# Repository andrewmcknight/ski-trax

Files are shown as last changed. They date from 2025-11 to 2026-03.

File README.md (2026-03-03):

# Ski-Trax

Ski-Trax is an embedded tracking node built around the Heltec WiFi LoRa 32 V3. The goal is a rugged device that skiers can use to find their friends/family on the slopes, without needing a phone with cell service.

## Hardware Stack
- **Main MCU:** Heltec WiFi LoRa 32 V3 (ESP32-S3 + SX1262)
- **GNSS:** SparkFun MAX-M10S breakout (I2C)
- **Display:** Adafruit 2.2" TFT (ILI9341 driver) connected through the Adafruit EYESPI breakout (SPI)
- **IMU:** Adafruit BNO055 9-DOF sensor (I2C)
- **Barometer:** Adafruit BMP390 (I2C)
- **Inputs/Outputs:** Three external buttons, piezo buzzer, TFT backlight PWM

## Pin Assignments
| Function | Heltec GPIO | Notes |
|---|---|---|
| I2C SDA | 47 | Shared by MAX-M10S, BNO055, BMP390 |
| I2C SCL | 48 | Shared by MAX-M10S, BNO055, BMP390 |
| TFT SCK | 3 | Hardware SPI via EyeSPI ribbon |
| TFT MOSI | 4 | Hardware SPI via EyeSPI ribbon |
| TFT CS | 7 | |
| TFT D/C | 5 | |
| TFT RST | 6 | |
| TFT Backlight PWM | 2 | Driven with LEDC PWM |
| Button – Dim | 40 | Input with pull-up |
| Button – Buzzer | 41 | Input with pull-up |
| Button – Brighten | 42 | Input with pull-up |
| Piezo Buzzer | 39 | LEDC PWM output |

> Note: LoRa radio is built into the Heltec board.

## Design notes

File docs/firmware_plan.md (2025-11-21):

## Ski-Trax Firmware Plan

### Goals
- Modular, testable firmware targeting Heltec WiFi LoRa 32 v3.
- Clean UI that leverages TFT assets (bitmaps for compass, icons, etc.).
- Feature set split into reusable services (pairing, networking, sensors, rendering).

---

## 1. System Architecture

### Core Tasks (FreeRTOS or cooperative scheduler)
1. **UI Task**
   - Drives TFT updates and handles button events.
   - Maintains a navigation state machine (Startup → Pairing → Session Lobby → Tracking).
2. **Sensor Task**
   - Polls GPS (MAX-M10S), IMU (BNO055), BMP390, battery ADC.
   - Normalizes sensor payloads and updates a shared `SensorSnapshot`.
3. **LoRa Session Task**
   - Handles discovery, pairing, and telemetry exchange.
   - Maintains a `SessionState` model accessible via queues.
4. **Storage Task (optional future)**
   - Persist user nickname, last session ID, calibration data, etc.

### Shared Data Models
- `DeviceProfile { uuid, nickname, hwVersion }`
- `SessionDescriptor { sessionId, hostNickname, memberCount, channel, lastSeen }`
- `PeerState { uuid, nickname, lastLocation, lastUpdateMs, stats }`
- `SensorSnapshot { gpsFix, timestamp, lat/lon, heading, velocity, altitude, batteryPct, batteryIconIdx, imuCalStatus }`

Use mutex-protected structs or message queues for cross-task communication.

---

## 2. Pairing Experience

### 2.1 Startup Flow
1. **Boot Splash**
   - Display logo + firmware version while services come online.
   - Show spinner / progress bar tied to sensor init.
2. **Landing Screen**
   - Two soft buttons: `Create Session` (left) and `Join Session` (right).
   - Always-on top bar showing time/battery/sensor status even during pairing.

### 2.2 Nickname Entry
1. Prompt user after selecting host/join.
2. UI concept: on-screen keyboard (grid) navigated with buttons or a scrollable list of preset names + an "Edit" action.
3. Persist nickname in NVS for future boots.

### 2.3 Session Creation (Host)
- **UI**
  - After nickname: display “Broadcasting Session…” with a session code (short hash) and a list of connected members.
  - Accept button to “Start Tracking” once at least one joiner is connected (optional skip allowed).
- **Networking**
  - Host advertises `SESSION_BEACON` every 500 ms with:
    - Session ID, host UUID, channel (LoRa frequency/spreading factor), session capabilities.
    - Current member count and uptime.
  - On join request, host replies with `SESSION_ACCEPT` including encryption keys/nonce if using secure packets.

### 2.4 Session Joining
- **UI**
  - Show scrolling list of detected sessions with strength indicators (RSSI) and host names.
  - Selecting a session sends join request; show progress indicator while waiting for `SESSION_ACCEPT`.
- **Networking**
  - Device sends `JOIN_PROBE` broadcast while scanning for beacons (listen cycle ~3s).
  - When beacons received, populate list (expire entries after ~5 s of silence).
  - On selecting session, send `JOIN_REQUEST {nickname, uuid, capabilities}`.
  - Await `SESSION_ACCEPT` (with session parameters) or `SESSION_DENY`.

### 2.5 Behind-the-Scenes Considerations
- Use unique 64-bit session IDs derived from host UUID + uptime millis.
- Include CRC and simple reliability (ack/retry) for pairing messages.
- Maintain state machine:
  - `Idle → NicknameEntry → (Host|Join) → Beaconing/Scanning → Lobby`.
- Provide hooks for future encryption key exchange (Diffie-Hellman or pre-shared key).

---

## 3. Tracking Experience

### 3.1 Session Lobby
- Shows roster tiles (nickname, status, last fix).
- Host can start/stop session; joiners wait for start signal.
- Behind the scenes, LoRa task flips from pairing channel to tracking channel and begins periodic position broadcast.

### 3.2 Tracking Screen Layout
```
┌───────────────────────────── Top Bar (persistent) ───────────────────────────┐
│   HH:MM (GPS)     Battery Icon     Sensor Icons (GNSS, IMU, LoRa, BMP)       │
├──────────────────────────────── Content Region ─────────────────────────────┤
│                                                                             │
│   [Peer Name + status]                                                      │
│   [Compass card (full screen) | overlays]                                   │
│   [Distance Icon + value | Relative Bearing text | Altitude icon + delta]   │
│   [Last update time (“15s ago”)]                                            │
│                                                                             │
├──────────────────────────── Bottom Buttons/Indicators ───────────────────────┤
│   [< Prev Member]           [Center/Home]           [Next Member >]          │
└─────────────────────────────────────────────────────────────────────────────┘
```

### 3.3 Button Mapping
- **Left/Right external buttons**: cycle through peers (wrap-around).
- **Center button**: toggles detail overlay (compass vs. map view in future).
- **Long-press combos**: e.g., hold left+right to open session menu.

### 3.4 Data Presentation
- **Compass**: use 36-direction bitmaps with overlays:
  - Add arrow/label pointing toward selected peer’s bearing relative to device heading.
  - Optionally show mini-map dot layout in future (reserve screen layer).
- **Distance/Altitude**: use custom icons (see Section 5) with values (e.g., `1.2 km`, `+80 m`).
- **Last Update**: relative time string (e.g., `Updated 12s ago`). If stale (>60s), highlight in yellow/red.
- **Peer Status**: include indicators for battery low, no fix, etc.

### 3.5 Networking (Tracking Mode)
- Each member broadcasts `TRACK_UPDATE` every X seconds (adjustable, default 2 s when moving, 5 s idle).
- Payload includes:
  - Timestamp, GPS lat/lon/alt, horizontal + vertical accuracy, heading, speed.
  - Sensor flags/battery level.
  - Sequence number for packet loss detection.
- Received updates stored in `PeerState` list; UI uses freshest data.
- Out-of-date peers flagged (greyed out in carousel).

---

## 4. Top Bar Design

### Contents
1. **GPS Time**
   - Use MAX-M10S time (UTC) converted to local offset (configurable).
   - Show `HH:MM` + small “GPS” icon if fix valid; flash or gray when no fix.
2. **Battery Icon**
   - Use one of 5 provided icons (Very Low, Low, Mid, High, Charging).
   - Battery ADC sampling handled by sensor task; smoothing filter to avoid jitter.
3. **Sensor Status Icons**
   - GNSS, IMU, BMP, LoRa, buttons/backlight.
   - Each icon has ON/OFF/Warning states (color-coded or using alternate bitmaps).

### Behavior
- Always rendered first each frame; UI task re-draws only when values change.
- Provide animation hook (e.g., blink LoRa icon when transmitting).

---

## 5. Custom Assets & Icons

### Required Assets
1. **Compass Needle Set**: 36 frames (already exist).
2. **Battery Icons**: 5 states (0%, 25%, 50%, 75%, 100% + charging overlay).
3. **Sensor Icons**:
   - GNSS lock/unlock.
   - IMU calibration status.
   - LoRa link (connected/searching).
   - BMP sensor status.
4. **Session & Menu Icons**:
   - Create session, join session buttons.
   - Nickname entry keyboard keys.
5. **Distance & Altitude Icons**:
   - Up/down arrows or mountain icon.
   - Distance circle or target icon.
6. **Misc**:
   - Status warnings (e.g., “No Fix”, “Low Battery”).
   - Soft button indicators for on-screen prompts.

### Asset Pipeline
- Store bitmaps in `code/main/src/assets/` as `const uint16_t[] PROGMEM`.
- Provide `assets_manifest.h` for centralized declarations; UI modules include via this manifest.
- Use `tools/png_to_bitmap.py` to convert new PNGs and keep aspect ratios consistent.

---

## 6. UI Navigation State Machine

```
BOOT
  └─► INIT (hardware checks, sensor init, asset preload)
        └─► LANDING (Create vs Join)
              ├─► NICKNAME_ENTRY
              │      └─► HOST_SETUP → LOBBY_HOST
              │                     └─► TRACKING
              └─► JOIN_SCAN → SESSION_LIST → LOBBY_GUEST → TRACKING
TRACKING
  └─► MENU (long-press) → SETTINGS / EXIT SESSION
```

- Each state has:
  - `enter()` for drawing static layout.
  - `update()` for periodic tasks.
  - `handleEvent(event)` for button/network callbacks.
- Allows future states (e.g., message view, map view) to be added cleanly.

---

## 7. Networking Protocol Summary

| Message | Direction | Purpose | Key Fields |
|---|---|---|---|
| `SESSION_BEACON`  | Host→All  | Advertise session availability | sessionId, hostName, channel, members, uptime |
| `JOIN_PROBE` | All→All | Trigger hosts to respond | uuid, nickname (optional) |
| `JOIN_REQUEST` | Joiner→Host | Request to enter session | uuid, nickname, fwVersion, capabilities |
| `SESSION_ACCEPT`  | Host→Joiner | Confirm join + share session params | sessionId, channel, encryption seed, member list  |
| `SESSION_DENY` | Host→Joiner | Reject join (full, auth fail) | reason code |
| `TRACK_UPDATE` | All↔All  | Share GPS/IMU status in session | timestamp, lat/lon/alt, heading, speed, battery |
| `HEARTBEAT` | All↔All  | Keepalive + version check | uptime, metrics |

- Use SX1262 raw packets via LoRa API; consider encryption/compression later.
- Each packet includes CRC and version field for compatibility.

---

## 8. Button & Input Handling

- Debounce + hold detection done centrally (button service).
- Emit high-level events: `BTN_LEFT_SHORT`, `BTN_RIGHT_LONG`, etc.
- UI states subscribe to events to change screens or trigger actions.
- Allows future expansion (e.g., double-tap for quick actions).

---

## 9. Settings & Future Proofing

- **Settings Menu** (accessible via long-press):
  - Units (metric/imperial).
  - Display brightness/backlight timeout.
  - Radio channel/power overrides.
  - Sensor calibration helper screens.
- **Modularity**:
  - Keep `ui/`, `sensors/`, `radio/`, `assets/`, `config/` directories.
  - Use interfaces (pure virtual classes or function pointers) to abstract hardware.
  - Provide test harness in `code/io_tests/` for each subsystem (e.g., pairing mock, UI emulator).

---

## 10. Constraints & Open Questions
- **Security**: No PIN/password protection for initial version.
- **Networking**: Point-to-point session only (no mesh); optimize for two devices but design protocol for up to 8 members max.
- **User Count**: Hard cap 8; UI should scale but initial validation can be done with 2 devices.
- **Units**: Imperial (feet/mph) by default; metric support can be added later.
- **Feature Scope**: Prioritize polished UX + core functionality over production-grade extras (logging, encryption, etc.).

Remaining questions:
1. Should joiners store last session info for auto-reconnect?
2. Any requirements for exporting activity logs/tracks later?
3. How should we visualize “inactive” peers (e.g., offline indicator)?

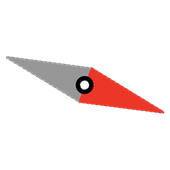
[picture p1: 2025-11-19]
images/compass/needles/needle_250.png

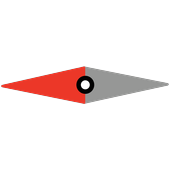
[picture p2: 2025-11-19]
images/compass/needles/needle_090.png

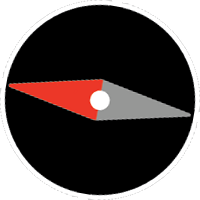
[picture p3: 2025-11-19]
images/compass/full/compass_080.png

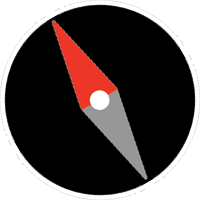
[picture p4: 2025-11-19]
images/compass/full/compass_030.png

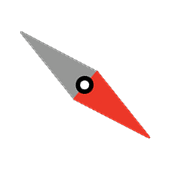
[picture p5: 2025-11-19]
images/compass/needles/needle_230.png

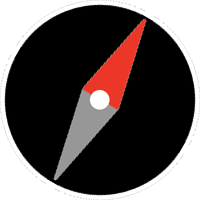
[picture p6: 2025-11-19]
images/compass/full/compass_330.png

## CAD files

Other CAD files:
3d-models/WiFi_LoRa32_V3.dwg

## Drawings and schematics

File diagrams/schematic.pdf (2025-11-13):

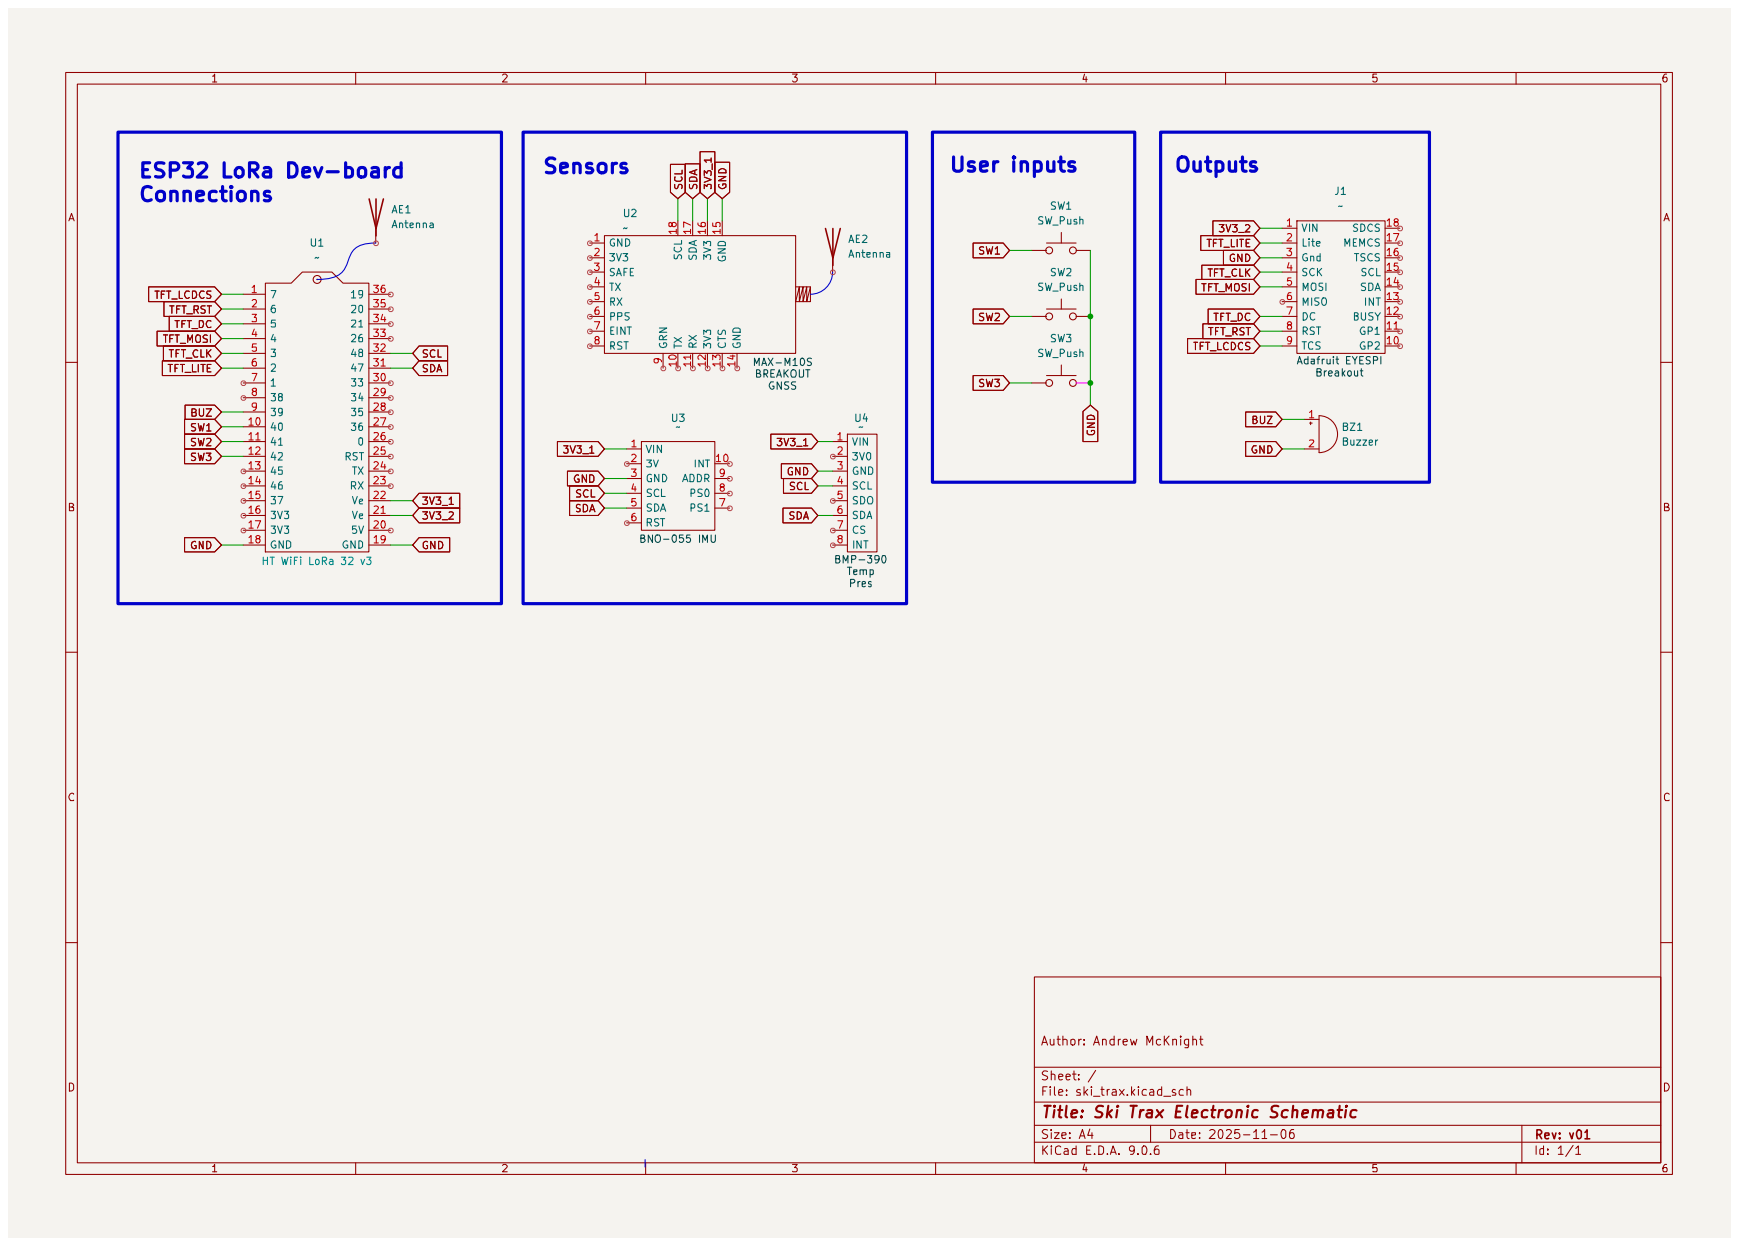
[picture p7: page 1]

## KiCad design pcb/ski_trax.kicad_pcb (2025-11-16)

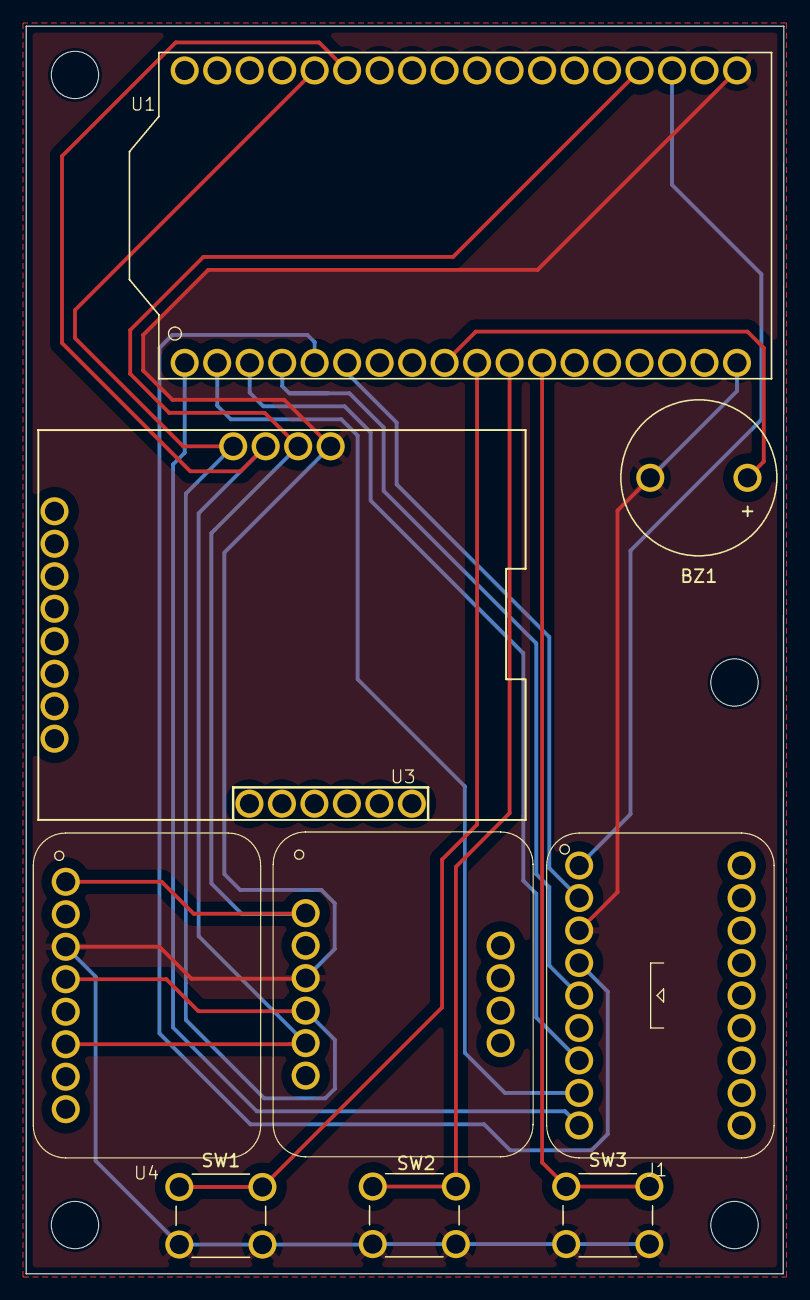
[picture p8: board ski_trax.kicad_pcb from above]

Board: 2 copper layers, 59.2 x 97.5 mm, 9 parts (0 on the bottom side), 15 nets.

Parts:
BZ1: Buzzer; Buzzer_12x9.5RM7.6
J1: Adafruit_EYESPI_Breakout
SW1, SW2, SW3: SW_Push; SW_PUSH_6mm
U1: Heltec_WiFi_LoRa_32_v3
U2: sparkfun_max_m10s_breakout
U3: Adafruit_BNO055
U4: Adafruit_BMP390

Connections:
3V3_1: U1.22 (Ve), U2.16 (3V3), U3.1 (VIN), U4.1 (VIN)
3V3_2: J1.1 (VIN), U1.21 (Ve)
BUZ: BZ1.1 (+), U1.9 (39)
GND: BZ1.2 (-), J1.3 (Gnd), SW1.1, SW2.1, SW3.1, U1.18 (GND), U1.19 (GND), U2.15 (GND), U3.3 (GND), U4.3 (GND)
SCL: U1.32 (48), U2.18 (SCL), U3.4 (SCL), U4.4 (SCL)
SDA: U1.31 (47), U2.17 (SDA), U3.5 (SDA), U4.6 (SDA)
SW1: SW1.2, U1.10 (40)
SW2: SW2.2, U1.11 (41)
SW3: SW3.2, U1.12 (42)
TFT_CLK: J1.4 (SCK), U1.5 (3)
TFT_DC: J1.7 (DC), U1.3 (5)
TFT_LCDCS: J1.9 (TCS), U1.1 (7)
TFT_LITE: J1.2 (Lite), U1.6 (2)
TFT_MOSI: J1.5 (MOSI), U1.4
TFT_RST: J1.8 (RST), U1.2 (6)

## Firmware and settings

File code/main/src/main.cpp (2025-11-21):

#include <Arduino.h>
#include <Wire.h>
#include <SPI.h>
#include <Adafruit_GFX.h>
#include <Adafruit_ILI9341.h>
#include <Adafruit_BMP3XX.h>
#include <Adafruit_BNO055.h>
#include <utility/imumaths.h>
#include <SparkFun_u-blox_GNSS_Arduino_Library.h>
#include <esp32-hal-ledc.h>
#include <LoRaWan_APP.h>
#include <cmath>
#include <cstdio>
#include <cstring>
#include <Fonts/FreeSans9pt7b.h>
#include <Fonts/FreeSansBold9pt7b.h>
#include <Fonts/FreeSansBold12pt7b.h>
#include <Fonts/FreeSansBold18pt7b.h>
#include "assets/icons/compass_20x20.h"
#include "assets/icons/pressure_20x20.h"
#include "assets/icons/satellite_22x22.h"
#include "assets/icons/bat0_44x18.h"
#include "assets/icons/bat25_44x18.h"
#include "assets/icons/bat50_44x18.h"
#include "assets/icons/bat75_44x18.h"
#include "assets/icons/bat100_44x18.h"
#include "assets/icons/altitude_44x18.h"
#include "assets/icons/distance_32x20.h"

#include "config/pins.h"
#include "assets/compass/compass_bg.h"
#include "assets/compass/needle/needle_000.h"
#include "assets/compass/needle/needle_010.h"
#include "assets/compass/needle/needle_020.h"
#include "assets/compass/needle/needle_030.h"
#include "assets/compass/needle/needle_040.h"
#include "assets/compass/needle/needle_050.h"
#include "assets/compass/needle/needle_060.h"
#include "assets/compass/needle/needle_070.h"
#include "assets/compass/needle/needle_080.h"
#include "assets/compass/needle/needle_090.h"
#include "assets/compass/needle/needle_100.h"
#include "assets/compass/needle/needle_110.h"
#include "assets/compass/needle/needle_120.h"
#include "assets/compass/needle/needle_130.h"
#include "assets/compass/needle/needle_140.h"
#include "assets/compass/needle/needle_150.h"
#include "assets/compass/needle/needle_160.h"
#include "assets/compass/needle/needle_170.h"
#include "assets/compass/needle/needle_180.h"
#include "assets/compass/needle/needle_190.h"
#include "assets/compass/needle/needle_200.h"
#include "assets/compass/needle/needle_210.h"
#include "assets/compass/needle/needle_220.h"
#include "assets/compass/needle/needle_230.h"
#include "assets/compass/needle/needle_240.h"
#include "assets/compass/needle/needle_250.h"
#include "assets/compass/needle/needle_260.h"
#include "assets/compass/needle/needle_270.h"
#include "assets/compass/needle/needle_280.h"
#include "assets/compass/needle/needle_290.h"
#include "assets/compass/needle/needle_300.h"
#include "assets/compass/needle/needle_310.h"
#include "assets/compass/needle/needle_320.h"
#include "assets/compass/needle/needle_330.h"
#include "assets/compass/needle/needle_340.h"
#include "assets/compass/needle/needle_350.h"

// --------------------------- Display & SPI ---------------------------------
constexpr uint32_t kTftSpiFrequency = 40000000UL;
constexpr uint16_t kScreenWidth = 240;
constexpr uint16_t kScreenHeight = 320;
constexpr uint16_t kTopBarHeight = 25;
constexpr uint16_t kNameBandTop = kTopBarHeight + 6;
constexpr uint16_t kNameBandHeight = 32;
constexpr uint16_t kCompassTopMargin = 8;
constexpr uint16_t kCompassBottomMargin = 4;
constexpr uint16_t kStatsRowHeight = 60;
constexpr uint16_t kCompassBgSize = 176;
constexpr uint16_t kNeedleSize = 170;
constexpr uint16_t kNeedleOffset = (kCompassBgSize - kNeedleSize) / 2;
constexpr uint16_t kMagentaKey = 0xF81F;

SPIClass tftSpi(HSPI);
Adafruit_ILI9341 tft(&tftSpi, Pins::TFT_DC, Pins::TFT_CS, Pins::TFT_RST);

// --------------------------- Sensors ---------------------------------------
Adafruit_BMP3XX bmp390;
Adafruit_BNO055 bno055(55, 0x28);
SFE_UBLOX_GNSS gnss;

// Live snapshot of sensors and derived values used by the UI and radio payloads.
struct SensorSnapshot {
  bool gpsReady = false;
  bool gpsFix = false;
  bool imuReady = false;
  bool bmpReady = false;
  double latitude = 0.0;
  double longitude = 0.0;
  float altitudeMeters = NAN;
  float groundSpeedMps = 0.0f;
  float headingDegrees = NAN;
  float imuHeading = NAN;
  uint8_t imuCalSys = 0;
  uint8_t imuCalMag = 0;
  float temperatureC = NAN;
  float pressurePa = NAN;
  uint32_t lastGpsFixMs = 0;
  uint8_t batteryPercent = 0;
};

SensorSnapshot sensorSnapshot;

// --------------------------- Compass Assets --------------------------------
struct NeedleFrame {
  const uint16_t* bitmap;
  uint16_t bearingDeg;
};

static const NeedleFrame kNeedleFrames[] = {
  {needle_000,   0},
  {needle_010,  10},
  {needle_020,  20},
  {needle_030,  30},
  {needle_040,  40},
  {needle_050,  50},
  {needle_060,  60},
  {needle_070,  70},
  {needle_080,  80},
  {needle_090,  90},
  {needle_100, 100},
  {needle_110, 110},
  {needle_120, 120},
  {needle_130, 130},
  {needle_140, 140},
  {needle_150, 150},
  {needle_160, 160},
  {needle_170, 170},
  {needle_180, 180},
  {needle_190, 190},
  {needle_200, 200},
  {needle_210, 210},
  {needle_220, 220},
  {needle_230, 230},
  {needle_240, 240},
  {needle_250, 250},
  {needle_260, 260},
  {needle_270, 270},
  {needle_280, 280},
  {needle_290, 290},
  {needle_300, 300},
  {needle_310, 310},
  {needle_320, 320},
  {needle_330, 330},
  {needle_340, 340},
  {needle_350, 350},
};
constexpr size_t kNeedleFrameCount = sizeof(kNeedleFrames) / sizeof(kNeedleFrames[0]);

// Handles positioning and partial redraw of the compass needle without repainting the background every frame.
struct CompassRenderer {
  bool backgroundDrawn = false;
  size_t activeNeedle = kNeedleFrameCount;
  int16_t bgX = 0;
  int16_t bgY = 0;
  int16_t needleX = 0;
  int16_t needleY = 0;

  void initLayout() {
    const int16_t areaTop = kNameBandTop + kNameBandHeight + kCompassTopMargin;
    const int16_t areaBottom = kScreenHeight - kStatsRowHeight - kCompassBottomMargin;
    const int16_t availHeight = areaBottom - areaTop;
    bgX = (kScreenWidth - kCompassBgSize) / 2;
    bgY = areaTop + (availHeight - kCompassBgSize) / 2;
    if (bgY < areaTop) {
      bgY = areaTop;
    }
    needleX = bgX + kNeedleOffset;
    needleY = bgY + kNeedleOffset;
  }

  void drawBackgroundOnce() {
    if (backgroundDrawn) {
      return;
    }
    initLayout();
    tft.drawRGBBitmap(bgX, bgY, compass_bg, kCompassBgSize, kCompassBgSize);
    backgroundDrawn = true;
  }

  void eraseNeedlePixels(size_t index) {
    if (index >= kNeedleFrameCount) {
      return;
    }
    tft.startWrite();
    for (uint16_t row = 0; row < kNeedleSize; ++row) {
      for (uint16_t col = 0; col < kNeedleSize; ++col) {
        const uint32_t idx = static_cast<uint32_t>(row) * kNeedleSize + col;
        uint16_t px = pgm_read_word(&(kNeedleFrames[index].bitmap[idx]));
        if (px == kMagentaKey) {
          continue;
        }
        const uint16_t bg = pgm_read_word(&(compass_bg[(row + kNeedleOffset) * kCompassBgSize + (col + kNeedleOffset)]));
        tft.writePixel(needleX + col, needleY + row, bg);
      }
    }
    tft.endWrite();
  }

  void drawNeedle(size_t index) {
    if (index >= kNeedleFrameCount) {
      return;
    }
    if (activeNeedle != index) {
      eraseNeedlePixels(activeNeedle);
    }
    tft.startWrite();
    for (uint16_t row = 0; row < kNeedleSize; ++row) {
      for (uint16_t col = 0; col < kNeedleSize; ++col) {
        const uint32_t idx = static_cast<uint32_t>(row) * kNeedleSize + col;
        uint16_t px = pgm_read_word(&(kNeedleFrames[index].bitmap[idx]));
        if (px == kMagentaKey) {
          continue;
        }
        tft.writePixel(needleX + col, needleY + row, px);
      }
    }
    tft.endWrite();
    activeNeedle = index;
  }

  void reset() {
    backgroundDrawn = false;
    activeNeedle = kNeedleFrameCount;
  }
};

CompassRenderer compassRenderer;

// --------------------------- Buttons ---------------------------------------
struct ButtonState {
  uint8_t pin = 0;
  bool pressed = false;
  bool lastReported = false;
  bool longReported = false;
  uint32_t changeMs = 0;
};

enum class ButtonId : uint8_t { Left, Center, Right };

struct ButtonEvent {
  ButtonId id;
  bool longPress;
};

// Polled button handler with debouncing, long-press detection, and a small event queue.
class ButtonInput {
 public:
  void begin() {
    initButton(btnLeft_, Pins::BUTTON_LEFT);
    initButton(btnCenter_, Pins::BUTTON_CENTER);
    initButton(btnRight_, Pins::BUTTON_RIGHT);
  }

  void poll() {
    pollButton(btnLeft_);
    pollButton(btnCenter_);
    pollButton(btnRight_);
  }

  bool popEvent(ButtonEvent* evt) {
    if (queueSize_ == 0) {
      return false;
    }
    *evt = queue_[0];
    for (size_t i = 1; i < queueSize_; ++i) {
      queue_[i - 1] = queue_[i];
    }
    --queueSize_;
    return true;
  }

 private:
  static constexpr uint32_t kLongPressMs = 600;
  static constexpr size_t kMaxQueue = 8;

  ButtonState btnLeft_{};
  ButtonState btnCenter_{};
  ButtonState btnRight_{};
  ButtonEvent queue_[kMaxQueue];
  size_t queueSize_ = 0;

  void initButton(ButtonState& state, uint8_t pin) {
    state.pin = pin;
    pinMode(pin, INPUT_PULLUP);
    state.pressed = !digitalRead(pin);
    state.lastReported = state.pressed;
    state.longReported = false;
    state.changeMs = millis();
  }

  void enqueue(ButtonId id, bool longPress) {
    if (queueSize_ >= kMaxQueue) {
      return;
    }
    queue_[queueSize_++] = ButtonEvent{id, longPress};
  }

  void pollButton(ButtonState& state) {
    bool pressed = !digitalRead(state.pin);
    if (pressed != state.pressed) {
      state.pressed = pressed;
      state.changeMs = millis();
      state.longReported = false;
    }
    const uint32_t now = millis();
    if (state.pressed && !state.longReported && (now - state.changeMs) >= kLongPressMs) {
      state.longReported = true;
      enqueue(buttonIdForPin(state.pin), true);
    }
    if (state.pressed != state.lastReported && (now - state.changeMs) > 20) {
      state.lastReported = state.pressed;
      if (!state.pressed && !state.longReported) {
        ButtonId id = buttonIdForPin(state.pin);
        enqueue(id, false);
      }
    }
  }

  static ButtonId buttonIdForPin(uint8_t pin) {
    if (pin == Pins::BUTTON_LEFT) {
      return ButtonId::Left;
    }
    if (pin == Pins::BUTTON_RIGHT) {
      return ButtonId::Right;
    }
    return ButtonId::Center;
  }
};

ButtonInput buttons;

// --------------------------- Battery Helpers -------------------------------
float batteryVoltage = 0.0f;
uint8_t batteryPercent = 0;

float readBatteryVoltage() {
  // Based on divider: 100k / (100k + 390k)
  // VBAT = Vadc * ((100 + 390) / 100) = Vadc * 4.9
  constexpr float kVoltageDividerRatio = 4.9f;

  const uint16_t raw = analogRead(Pins::BATTERY_ADC);
  const float adcVoltage = (static_cast<float>(raw) / 4095.0f) * 3.3f;
  return adcVoltage * kVoltageDividerRatio;
}

uint8_t voltageToPercent(float volts) {
  // Clamp typical Li-ion usable range
  const float clamped = constrain(volts, 3.3f, 4.2f);
  const float pct = (clamped - 3.3f) / (4.2f - 3.3f);
  return static_cast<uint8_t>(pct * 100.0f);
}

// --------------------------- UI State Machine ------------------------------
enum class AppScreen {
  Splash,
  PairChoice,
  NicknameEntry,
  HostLobby,
  JoinDiscover,
  Tracking,
};

AppScreen currentScreen = AppScreen::Splash;
bool screenDirty = true;
uint32_t splashStartMs = 0;
bool hostSelected = true;
size_t selectedSessionIndex = 0;
size_t selectedPeerIndex = 0;

// --------------------------- LoRa Networking -------------------------------
constexpr uint8_t kMaxPeers = 8;
constexpr size_t kNicknameMax = 12;
constexpr uint32_t kBeaconIntervalMs = 1000;
constexpr uint32_t kDiscoveryExpiryMs = 5000;
constexpr uint32_t kTrackUpdateIntervalMs = 2000;
constexpr uint8_t kProtocolVersion = 1;

enum class PacketType : uint8_t {
  Beacon = 1,       // Host advertises session availability and member count.
  JoinRequest = 2,  // Client asks to join a specific session.
  JoinAccept = 3,   // Host approves a join request and informs the requester.
  TrackUpdate = 4,  // Position/headings broadcast to peers during tracking.
  Heartbeat = 5,    // Reserved keepalive/health message for future use.
};

// Small fixed header shared by all packet types for validation and routing.
struct PacketHeader {
  uint8_t magic0 = 'S';
  uint8_t magic1 = 'T';
  uint8_t version = kProtocolVersion;
  PacketType type = PacketType::Beacon;
  uint32_t sessionId = 0;
  uint32_t senderId = 0;
};
static_assert(sizeof(PacketHeader) == 12, "PacketHeader must stay compact");

// Broadcast advertisement from a host so others can discover active sessions.
struct BeaconInfo {
  uint32_t sessionId = 0;
  uint32_t hostId = 0;
  char hostName[kNicknameMax + 1] = {0};
  uint8_t memberCount = 0;
  int16_t rssi = 0;
  uint32_t lastSeenMs = 0;
};

// State we track for each peer we are following in a session.
struct PeerState {
  uint32_t deviceId = 0;
  char nickname[kNicknameMax + 1] = {0};
  double latitude = 0.0;
  double longitude = 0.0;
  float altitudeMeters = 0.0f;
  float headingDeg = NAN;
  uint8_t batteryPercent = 0;
  uint32_t lastUpdateMs = 0;
};

// Overall session membership and role tracking.
struct SessionState {
  bool isHost = false;
  bool active = false;
  uint32_t sessionId = 0;
  char hostName[kNicknameMax + 1] = {0};
  PeerState peers[kMaxPeers];
  size_t peerCount = 0;
};

SessionState sessionState;
uint32_t pendingAcceptDeviceId = 0;
uint8_t pendingAcceptRetries = 0;
uint32_t lastAcceptSendMs = 0;
BeaconInfo discoveredSessions[kMaxPeers];
size_t discoveredCount = 0;

uint32_t deviceId = 0;
char nickname[kNicknameMax + 1] = "SKIER";
bool joinRequestPending = false;
uint32_t pendingJoinSessionId = 0;

enum class AppScreen;
void setScreen(AppScreen next);
void sendJoinAccept(uint32_t targetDeviceId);
extern bool screenDirty;

static RadioEvents_t RadioEvents;
typedef enum {
  LOWPOWER,
  STATE_RX,
  STATE_TX,
} States_t;
States_t radioState = STATE_RX;
bool radioPendingTx = false;
uint8_t txBuffer[160];
uint16_t txLength = 0;
uint32_t lastBeaconSend = 0;
uint32_t lastTrackSend = 0;
uint32_t lastRadioRxMs = 0;

// -------------- LoRa config ----------------
constexpr uint32_t RF_FREQUENCY = 915000000UL; 
// Carrier frequency in Hz. 915 MHz is the ISM band used in North America.

constexpr int8_t TX_OUTPUT_POWER = 14;
// Transmit power in dBm. Higher = longer range, more battery use.
// 14 dBm (~25 mW) is typical and legal for US LoRa modules.

constexpr uint8_t LORA_BANDWIDTH = 0;
// LoRa bandwidth index. 0 = 125 kHz, 1 = 250 kHz, 2 = 500 kHz.
// Lower bandwidth = better range, slower data rate.

constexpr uint8_t LORA_SPREADING_FACTOR = 7;
// Spreading factor (SF7–SF12). Higher SF = more range & robustness, but slower.
// SF7 is fast and commonly used for mobile devices.

constexpr uint8_t LORA_CODINGRATE = 1;
// Error coding rate. 1 = 4/5, 2 = 4/6, 3 = 4/7, 4 = 4/8.
// Higher CR = more redundancy, better reliability, slower throughput.

constexpr uint16_t LORA_PREAMBLE_LENGTH = 8;
// Number of preamble symbols before the payload. Affects detection reliability.
// 8 is standard; longer improves detection in noisy environments at cost of airtime.

constexpr uint16_t LORA_SYMBOL_TIMEOUT = 0;
// Symbol timeout for Rx window. 0 = no timeout (continuous receive).
// Used mostly in LoRaWAN; usually left at 0 for point-to-point.

constexpr bool LORA_FIX_LENGTH_PAYLOAD_ON = false;
// false = variable-length packets (normal).
// true = fixed-length packets (rarely used unless protocol demands it).

constexpr bool LORA_IQ_INVERSION_ON = false;
// IQ inversion toggles the LoRa modulation baseband phase.
// false = standard LoRa packets.
// true = used only for special networks (e.g., LoRaWAN downlinks or sniffing).

void onTxDone();
void onTxTimeout();
void onRxDone(uint8_t* payload, uint16_t size, int16_t rssi, int8_t snr);

void setupRadio() {
  RadioEvents.TxDone = onTxDone;
  RadioEvents.TxTimeout = onTxTimeout;
  RadioEvents.RxDone = onRxDone;

  Mcu.begin(HELTEC_BOARD, SLOW_CLK_TPYE);
  Radio.Init(&RadioEvents);
  Radio.SetChannel(RF_FREQUENCY);
  Radio.SetTxConfig(MODEM_LORA, TX_OUTPUT_POWER, 0, LORA_BANDWIDTH,
                    LORA_SPREADING_FACTOR, LORA_CODINGRATE,
                    LORA_PREAMBLE_LENGTH, LORA_FIX_LENGTH_PAYLOAD_ON,
                    true, 0, 0, LORA_IQ_INVERSION_ON, 3000);
  Radio.SetRxConfig(MODEM_LORA, LORA_BANDWIDTH, LORA_SPREADING_FACTOR,
                    LORA_CODINGRATE, 0, LORA_PREAMBLE_LENGTH,
                    LORA_SYMBOL_TIMEOUT, LORA_FIX_LENGTH_PAYLOAD_ON,
                    0, true, 0, 0, LORA_IQ_INVERSION_ON, true);
  radioState = STATE_RX;
  Radio.Rx(0);
}

// Write a common packet header into the provided buffer.
bool encodeHeader(uint8_t* buffer, size_t capacity, PacketType type, uint32_t sessionId) {
  if (capacity < sizeof(PacketHeader)) {
    return false;
  }
  PacketHeader hdr;
  hdr.type = type;
  hdr.sessionId = sessionId;
  hdr.senderId = deviceId;
  memcpy(buffer, &hdr, sizeof(PacketHeader));
  return true;
}

// Validate header contents and unpack it into the provided struct.
bool decodeHeader(const uint8_t* data, size_t size, PacketHeader* out) {
  if (size < sizeof(PacketHeader)) {
    return false;
  }
  memcpy(out, data, sizeof(PacketHeader));
  if (out->magic0 != 'S' || out->magic1 != 'T') {
    return false;
  }
  if (out->version != kProtocolVersion) {
    return false;
  }
  return true;
}

// Stage bytes for transmission the next time the radio is idle.
void queueTx(const uint8_t* data, uint16_t len) {
  if (len > sizeof(txBuffer)) {
    return;
  }
  memcpy(txBuffer, data, len);
  txLength = len;
  radioPendingTx = true;
}

// Processes pending TX/RX requests and advances the radio state machine.
void serviceRadio() {
  // Always process IRQs so state transitions complete even if a TX is queued.
  Radio.IrqProcess();

  if (radioPendingTx && radioState != STATE_TX) {
    Radio.Send(txBuffer, txLength);
    radioState = STATE_TX;
    radioPendingTx = false;
    return;
  }
  if (radioState == STATE_RX) {
    Radio.Rx(0);
  }
}

void onTxDone() {
  radioState = STATE_RX;
  Radio.Rx(0);
}

void onTxTimeout() {
  radioState = STATE_RX;
  Radio.Rx(0);
}

// Record a host advertisement so the join UI can display it.
void handleBeacon(const PacketHeader& header, const uint8_t* payload, uint16_t size, int16_t rssi) {
  if (size < sizeof(PacketHeader) + 1 + kNicknameMax) {
    return;
  }
  BeaconInfo info{};
  info.sessionId = header.sessionId;
  info.hostId = header.senderId;
  info.memberCount = payload[sizeof(PacketHeader)];
  strncpy(info.hostName, reinterpret_cast<const char*>(payload + sizeof(PacketHeader) + 1), kNicknameMax);
  info.hostName[kNicknameMax] = '\0';
  info.rssi = rssi;
  info.lastSeenMs = millis();

  bool updated = false;
  bool changed = false;
  for (size_t i = 0; i < discoveredCount; ++i) {
    if (discoveredSessions[i].sessionId == info.sessionId) {
      changed = (discoveredSessions[i].memberCount != info.memberCount) ||
                (discoveredSessions[i].rssi != info.rssi) ||
                (strncmp(discoveredSessions[i].hostName, info.hostName, kNicknameMax) != 0);
      discoveredSessions[i] = info;
      updated = true;
      break;
    }
  }
  if (!updated && discoveredCount < kMaxPeers) {
    discoveredSessions[discoveredCount++] = info;
    changed = true;
  }
  if (changed && currentScreen == AppScreen::JoinDiscover) {
    screenDirty = true;
  }
}

void handleJoinAccept(const PacketHeader& header, const uint8_t* payload, uint16_t size) {
  if (sessionState.active) {
    return;
  }
  if (size < sizeof(PacketHeader) + sizeof(uint32_t) + kNicknameMax) {
    return;
  }
  const uint8_t* ptr = payload + sizeof(PacketHeader);
  uint32_t targetId = 0;
  memcpy(&targetId, ptr, sizeof(uint32_t));
  ptr += sizeof(uint32_t);
  if (targetId != deviceId) {
    return;
  }
  sessionState.active = true;
  sessionState.isHost = false;
  sessionState.sessionId = header.sessionId;
  strncpy(sessionState.hostName, reinterpret_cast<const char*>(ptr), kNicknameMax);
  sessionState.hostName[kNicknameMax] = '\0';

  // Seed peer list with host so the tracking screen shows it immediately.
  sessionState.peerCount = 0;
  if (sessionState.peerCount < kMaxPeers) {
    PeerState& hostPeer = sessionState.peers[sessionState.peerCount++];
    hostPeer.deviceId = header.senderId;
    strncpy(hostPeer.nickname, sessionState.hostName, kNicknameMax);
    hostPeer.nickname[kNicknameMax] = '\0';
    hostPeer.lastUpdateMs = millis();
  }

  joinRequestPending = false;
  lastTrackSend = 0;  // Force an immediate track update from the joiner.
  setScreen(AppScreen::Tracking);
}
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
void loop() {
  buttons.poll();
  ButtonEvent evt;
  while (buttons.popEvent(&evt)) {
    handleButtonEvent(evt);
  }

  const uint32_t now = millis();
  if (currentScreen == AppScreen::Splash && now - splashStartMs > 2000) {
    setScreen(AppScreen::PairChoice);
  }

  static uint32_t lastSensorMs = 0;
  if (now - lastSensorMs > 100) {
    lastSensorMs = now;
    updateBno();
    updateBmp();
    updateGnss();
    updateBattery();
  }

  cleanupExpiredSessions();

  if (sessionState.isHost && (currentScreen == AppScreen::HostLobby || currentScreen == AppScreen::Tracking)) {
    processHostLogic();
  }
  if (sessionState.active && currentScreen == AppScreen::Tracking) {
    processTrackingLogic();
  }

  serviceRadio();

  if (screenDirty) {
    renderCurrentScreen();
  }

  // Incremental UI updates without full-screen redraws.
  drawTopBar();
  if (currentScreen == AppScreen::Tracking) {
    drawTracking(false);
  }
}

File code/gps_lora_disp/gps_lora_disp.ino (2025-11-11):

/* (OLD, outdated!!!)
 * Heltec Wireless Tracker - GPS Position Sharing via LoRa with ILI9341 Display
 *
 * Hardware Connections:
 * ILI9341 TFT Display to Wireless Tracker:
 * - VCC   -> 3V3
 * - GND   -> GND
 * - CS    -> GPIO7
 * - RESET -> GPIO6
 * - DC    -> GPIO5
 * - MOSI  -> GPIO4
 * - SCK   -> GPIO17
 * - LED   -> 3V3 (with 100-150Ω resistor if needed)
 * 
 */

#include "Arduino.h"
#include "LoRaWan_APP.h"
#include "HT_TinyGPS++.h"
#include <Adafruit_GFX.h>
#include <Adafruit_ILI9341.h>
#include <SPI.h>

// ILI9341 Pin Configuration
#define TFT_CS      7
#define TFT_DC      5
#define TFT_RST     6
#define TFT_MOSI    4
#define TFT_SCK     19

// LoRa Configuration
#define RF_FREQUENCY                                915000000 // Hz
#define TX_OUTPUT_POWER                             14        // dBm
#define LORA_BANDWIDTH                              0         // 125 kHz
#define LORA_SPREADING_FACTOR                       7         // SF7
#define LORA_CODINGRATE                             1         // 4/5
#define LORA_PREAMBLE_LENGTH                        8
#define LORA_SYMBOL_TIMEOUT                         0
#define LORA_FIX_LENGTH_PAYLOAD_ON                  false
#define LORA_IQ_INVERSION_ON                        false
#define RX_TIMEOUT_VALUE                            1000
#define BUFFER_SIZE                                 50

// GPS Configuration
#define VGNSS_CTRL 3

// Color Definitions (Modern UI Palette)
#define COLOR_BG           0x0000  // Black background
#define COLOR_PRIMARY      0x07FF  // Cyan
#define COLOR_SECONDARY    0xFD20  // Orange
#define COLOR_SUCCESS      0x07E0  // Green
#define COLOR_WARNING      0xFFE0  // Yellow
#define COLOR_ERROR        0xF800  // Red
#define COLOR_TEXT         0xFFFF  // White
#define COLOR_TEXT_DIM     0x7BEF  // Gray
#define COLOR_PANEL_BG     0x2104  // Dark gray panel

// Objects
TinyGPSPlus GPS;
Adafruit_ILI9341 tft = Adafruit_ILI9341(TFT_CS, TFT_DC, TFT_MOSI, TFT_SCK, TFT_RST);

// LoRa Variables
char txpacket[BUFFER_SIZE];
char rxpacket[BUFFER_SIZE];
static RadioEvents_t RadioEvents;

typedef enum {
    LOWPOWER,
    STATE_RX,
    STATE_TX
} States_t;

States_t state;
int16_t Rssi = 0;

// GPS Position Storage
struct Position {
    double lat;
    double lon;
    bool valid;
    unsigned long lastUpdate;
};

Position localPos = {0, 0, false, 0};
Position remotePos = {0, 0, false, 0};

// Function Prototypes
void OnTxDone(void);
void OnTxTimeout(void);
void OnRxDone(uint8_t *payload, uint16_t size, int16_t rssi, int8_t snr);
void updateGPS();
void updateDisplay();
void drawStatusBar();
void drawPositionPanel(const char* title, Position& pos, int y, uint16_t color);
void drawRelativePosition();
void drawCompass(int centerX, int centerY, int radius, double bearing);
double calculateDistance(double lat1, double lon1, double lat2, double lon2);
double calculateBearing(double lat1, double lon1, double lat2, double lon2);
String formatCoordinate(double coord, bool isLat);
String formatDistance(double meters);
String getDirectionString(double bearing);

void setup() {
    Serial.begin(115200);
    
    // Initialize ILI9341 Display
    tft.begin();
    tft.setRotation(0);  // Portrait mode (240x320)
    tft.fillScreen(COLOR_BG);
    
    // Show splash screen
    tft.setTextColor(COLOR_PRIMARY);
    tft.setTextSize(3);
    tft.setCursor(30, 100);
    tft.println("GPS TRACKER");
    
    tft.setTextColor(COLOR_TEXT_DIM);
    tft.setTextSize(1);
    tft.setCursor(60, 140);
    tft.println("LoRa Position");
    tft.setCursor(75, 150);
    tft.println("Sharing");
    
    tft.setTextColor(COLOR_SECONDARY);
    tft.setTextSize(1);
    tft.setCursor(70, 180);
    tft.println("Initializing...");
    
    delay(2000);
    
    // Initialize GPS
    pinMode(VGNSS_CTRL, OUTPUT);
    digitalWrite(VGNSS_CTRL, HIGH);
    Serial1.begin(115200, SERIAL_8N1, 33, 34);
    
    // Initialize LoRa
    Mcu.begin(HELTEC_BOARD, SLOW_CLK_TPYE);
    
    RadioEvents.TxDone = OnTxDone;
    RadioEvents.TxTimeout = OnTxTimeout;
    RadioEvents.RxDone = OnRxDone;
    
    Radio.Init(&RadioEvents);
    Radio.SetChannel(RF_FREQUENCY);
    Radio.SetTxConfig(MODEM_LORA, TX_OUTPUT_POWER, 0, LORA_BANDWIDTH,
                      LORA_SPREADING_FACTOR, LORA_CODINGRATE,
                      LORA_PREAMBLE_LENGTH, LORA_FIX_LENGTH_PAYLOAD_ON,
                      true, 0, 0, LORA_IQ_INVERSION_ON, 3000);
    
    Radio.SetRxConfig(MODEM_LORA, LORA_BANDWIDTH, LORA_SPREADING_FACTOR,
                      LORA_CODINGRATE, 0, LORA_PREAMBLE_LENGTH,
                      LORA_SYMBOL_TIMEOUT, LORA_FIX_LENGTH_PAYLOAD_ON,
                      0, true, 0, 0, LORA_IQ_INVERSION_ON, true);
    
    state = STATE_RX;
    
    // Initial display setup
    tft.fillScreen(COLOR_BG);
    delay(500);
}

void loop() {
    // Update GPS position
    updateGPS();
    
    // State machine for LoRa communication
    switch(state) {
        case STATE_TX:
            // Always send a packet - either coordinates or "NOFIX"
            if (localPos.valid) {
                sprintf(txpacket, "%.6f,%.6f", localPos.lat, localPos.lon);
                Serial.printf("Sending: %s\r\n", txpacket);
            } else {
                sprintf(txpacket, "NOFIX");
                Serial.println("Sending: NOFIX");
            }
            Radio.Send((uint8_t *)txpacket, strlen(txpacket));
            state = LOWPOWER;
            break;
            
        case STATE_RX:
            Serial.println("RX mode");
            Radio.Rx(0);
            state = LOWPOWER;
            break;
            
        case LOWPOWER:
            Radio.IrqProcess();
            break;
    }
    
    // Update display periodically
    static unsigned long lastDisplayUpdate = 0;
    if (millis() - lastDisplayUpdate > 1000) {
        updateDisplay();
        lastDisplayUpdate = millis();
    }
    
    // Transmit periodically (every 5 seconds)
    static unsigned long lastTx = 0;
    if (millis() - lastTx > 5000 && state == LOWPOWER) {
        state = STATE_TX;
        lastTx = millis();
    }
}

void updateGPS() {
    while (Serial1.available() > 0) {
        char c = Serial1.read();
        if (GPS.encode(c)) {
            if (GPS.location.isValid()) {
                localPos.lat = GPS.location.lat();
                localPos.lon = GPS.location.lng();
                localPos.valid = true;
                localPos.lastUpdate = millis();
            }
        }
    }
}

void updateDisplay() {
    tft.fillScreen(COLOR_BG);
    
    // Draw status bar
    drawStatusBar();
    
    // Draw local position panel
    drawPositionPanel("LOCAL", localPos, 25, COLOR_PRIMARY);
    
    // Draw remote position panel
    drawPositionPanel("REMOTE", remotePos, 130, COLOR_SECONDARY);
    
    // Draw relative position (distance & bearing)
    if (localPos.valid && remotePos.valid && 
        (millis() - remotePos.lastUpdate < 30000)) {
        drawRelativePosition();
    }
}
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

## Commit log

2025-11-10 Update repo structure
    [WiFi_LoRa32_V3.dwg]
2025-11-11 Update EyeSPI TFT pin map for Heltec WiFi LoRa 32 V3
2025-11-13 Add PCB files
    [ski_trax.kicad_pcb, ski_trax.kicad_sch]
2025-11-16 Update PCB files
    [ski_trax.kicad_pcb, ski_trax_v01.kicad_pcb]
2025-11-21 Fixed joey and molly tracking
    [joey_tracker.ino, molly_tracker.ino]
